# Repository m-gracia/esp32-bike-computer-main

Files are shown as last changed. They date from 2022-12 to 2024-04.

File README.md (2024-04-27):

# A motorcycle computer based on ESP32

## Contents

- [Synopsis](#synopsis)
- [Features](#features)
- [Part List](#part-list)
- [How to build one](#how-to-build-one)
- [Schemes and connections](#schemes-and-connections)
- [Improvements list](#improvements-list)
- [Acknowledgements](#acknowledgements)
- [Disclaimer](#disclaimer)

## Synopsis

A small homemade motorcycle computer based on ESP32 controller to show some usefull information.
The project has been done thinking on the modularity, so new features can be added (or removed).

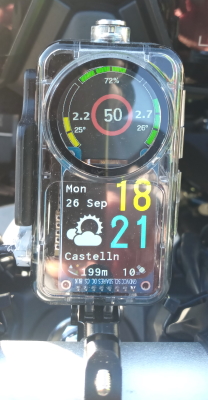
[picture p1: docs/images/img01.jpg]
ESP32 bike computer
<br>
*ESP32 bike computer mounted on a Yamaha Tracer 9*

## Features

- Android phone connection using mitchwongho application ([see acknowledgements](#acknowledgements)):
    - Shows the phone battery level.
    - Shows message alerts (Whatssapp, Telegram, SMS...).
- Tire pressure level, temperature and low battery alert from TPMS BLE sensors.
- Date, time and altitude from GPS.
- Weather prediction from OpenWeatherMap.
- Speed limit and street name from Microsoft Maps.
- Sends GPS latitude and longitude to a web server.
- Shows the location from the web server on a map.

### Other features not implemented

Some features have been removed from this version because there are not longer needed:

- Temperature using a waterproof DS1820
- ECU connection to KDS system (my old bike was a kawasaky). Here are some good information for those interested:
    - https://github.com/aster94/Keyword-Protocol-2000
    - https://github.com/HerrRiebmann/KDS2Bluetooth

## Part list

- **Wemos ESP32-S3 mini**<br>
    It could work with other ESP32 boards but I have chose this for the small size. Be sure to choose one with two cores, don't use a ESP32-C3 or ESP32-S2. I have use ESP32 mini D1 boards on other proyects, but the power IC included on some cheap boards doesn't provide enought power to keep wifi and bluetooth at the same time.
    
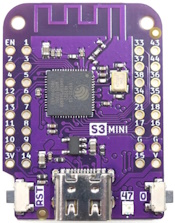
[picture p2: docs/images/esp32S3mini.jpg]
ESP32-S3 mini
    

- **GPS board Neo6M**<br>
    Don't forget to choose an apropiate antenna. It should work too with other smaller board like ATGM336H.

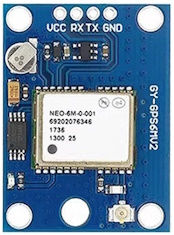
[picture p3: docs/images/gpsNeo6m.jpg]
Neo6M
    

- **SPI TFT**<br>
    One round 240x240 1,28" based on GC9A01 chip, and other square 240x280 1,69" based on ST7789 chip. These are cheap, fits on the case and they can be seen pretty clear under the sun light.

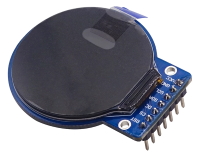
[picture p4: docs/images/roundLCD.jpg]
GC9A01 1,28" round LCD
    
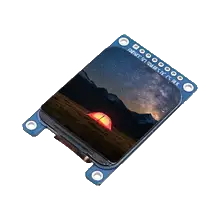
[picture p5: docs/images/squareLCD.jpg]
ST7789 1,69" square LCD
    

- **DJI Action2 case**<br>
    It is waterproof, both LCD's fits inside and you can remove one of the buttons to pass the cable through it. It has a standard gopro clip for holding it wherever you want. Choose the bracket that fits you better.

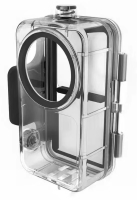
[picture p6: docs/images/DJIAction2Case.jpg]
DJI Action2 case
    
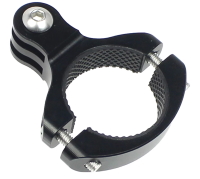
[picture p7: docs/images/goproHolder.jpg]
GoPro Holder
    

- **BLE 4.0 TPMS**<br>
    Bluetooth BLE 4.0 TPMS to control the tire pressure for Android / IOS application. Do not use BLE 5.0 model, is not supported by ESP32 at this moment.
    
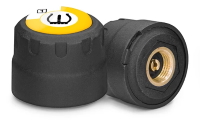
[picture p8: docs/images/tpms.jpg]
BLE4 TPMS
    

- **4G Wifi USB dongle**<br>
    USB Wifi - 4G router configured to create a hotspot for Internet connection. Must be connected to a USB connection on the bike.

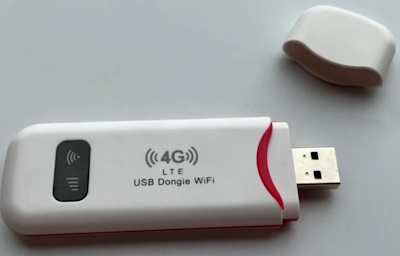
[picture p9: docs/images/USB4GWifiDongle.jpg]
USB 4G wifi router
    

- **Other stuff**
    - 2 * 8 pin 5cm dupond cables for LCDs.
    - 2 * 3x7cm PCB prototype breadboards.
    - USB male connector
    - Black USB-C cable.
    - Iron soldering kit.
    - Small silica gel bag for the LCD case. (Optional).    
    - Silicone thermal gun for sealing the junctions. (Optional).

## How to build one

1. Set a **public web server** to receive the information from the GPS and draw the route on a map.
If you do not want or need this function you can forget this step and comment the following line on "src/gprs.cpp" -> useGPRS():
```
// sendLocation();
```

Otherwise: 
- Download the files from [webpage](webpage) folder.
- Edit the sql scheme file, set your passwords and create a MariaDB database with the scheme and data to store the information.
- Edit the php files with your database server information.
- Save both php files on a folder served by the web server.

2. Get your OpenWeatherMap and Bing Maps API keys. You have to sign up on both services but the free tier should be enought.
     - https://openweathermap.org/api
     - https://www.bingmapsportal.com

3. Get all components and stuff listed below. They could be obtained from "all purpose" web pages like Aliexpress or Amazon.

4. Set your VCode + Platformio environment with the project from esp32-bike-computer-main folder. This step is too long to describe here and there is a lot of information on internet about how to do it :wink:
     - Create a "include/secrets.h" file and fill it with your data. E.g:
     ```
    #define TPMSMAC_FRONT "be:be:ca:fe:be:be"   //TPMS Front MAC Address
    #define TPMSMAC_REAR "ca:fe:be:be:ca:fe"    //TPMS Rear MAC Address
    #define HTTP_SERVER "my.server.com"
    #define HTTP_PATH "/bikefiles"   // Should begin with "/" and end without it
    #define WEATHER_APIKEY "yourOpenweathermapsAPIKey"
    #define WEATHER_CITYID "3104324"    // Zaragoza,ES Look for your location: https://www.openweathermap.org/find
    #define MAPS_APIKEY "yourBingMapsAPIKey"
    #define WEB_PASS "user_id0_pass_set_on_the_database"
    #define WIFI_SSID01 "SSID01_NAME"       // Configured on USB 4G Dongle
    #define WIFI_PASS01 "SSID01_PASSWORD"   // Configured on USB 4G Dongle
    #define WIFI_SSID02 "SSID02_NAME"       // Alternative. Eg: Phone hotspot
    #define WIFI_PASS02 "SSID02_PASSWORD"   // Alternative. Eg: Phone hotspot
     ```
     - Take a look on "include/my_def.h" and change some values if necessary:
     ``` 
     #define BT_DEVICE_NAME "Jarvis"     // BLE device name
     static unsigned char tpmsBatteyLow = 5;  // TPMS Battery low level
     static unsigned char tpmsLevelX = XX;    // TPMS Pressure levels
     #define TFT_TIMEMESSAGE 7000    // Phone alert message show time (7 sec)
     static TimeChangeRule CEST = {"CEST", Last, Sun, Mar, 2, 120};     // Central European Summer Time
     static TimeChangeRule CET = {"CET ", Last, Sun, Oct, 3, 60};       // Central European Standard Time

     ```
     - Compile and upload it to the ESP32. 
     - Upload the "data" folder files to ESP32 SPIFFS.

5. Build the PCB following the [schemes/main_v1.fzz](schemes/main_v1.fzz). Only the outer pins need to be solder.
     - [ESP32-S3 pinout](docs/esp32S3_pinout.png)

## Schemes and connections
There are some [Fritzing](https://fritzing.org/) schemes located on the [schemes](schemes) folder. They are designed for soldering on a quick breadboard.

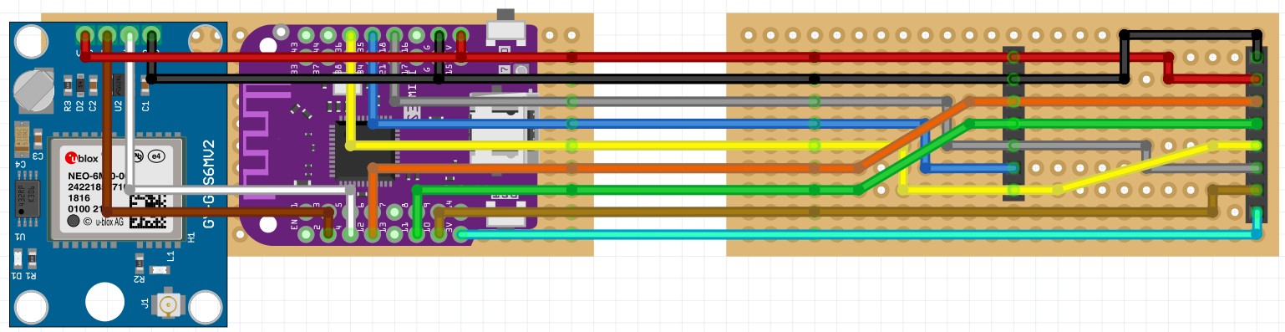
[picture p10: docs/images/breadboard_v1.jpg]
Breadboard Scheme


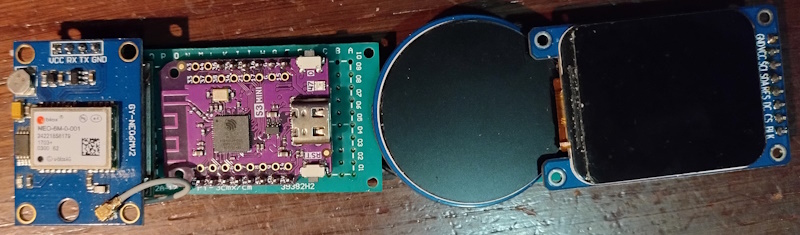
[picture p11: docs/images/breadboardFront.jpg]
Breadboard Front with plastic support


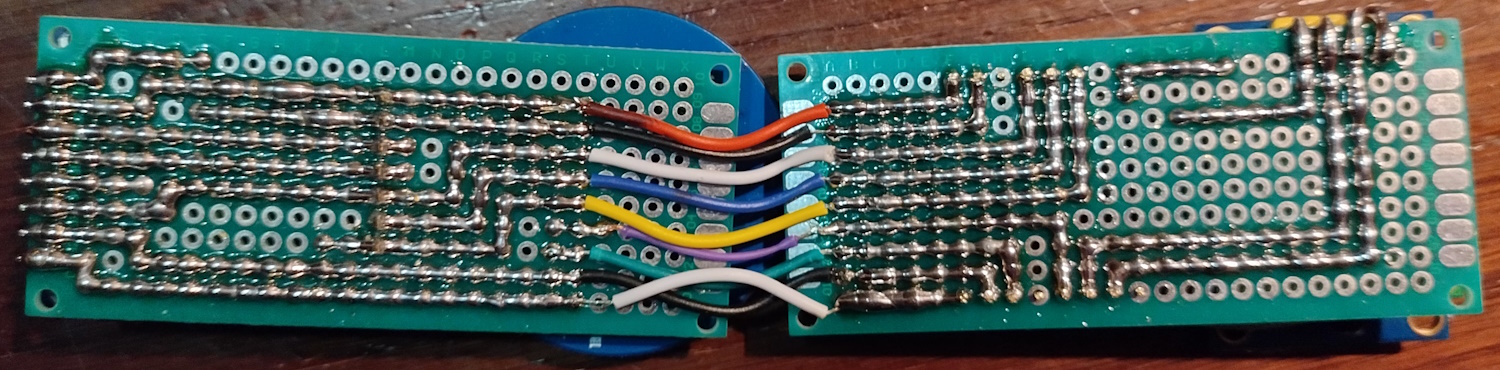
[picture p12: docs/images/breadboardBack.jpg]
Breadboard back


The connectors placement on the board are:
- Neo6M GPS: W10-T10
- ESP32 up: K10-F10
- Square LCD: "A" side external pins
- Round LCD: L9-L3

## Improvements list

- **Kickstand alert**<br>
    Using and ELM327 to communicate with the ECU, but I am not able to find the correct OBD PID. There are some projects to help with it, like: https://github.com/PowerBroker2/ELMduino

- **Turn by turn indications**<br>
    I am not able to find or build an application to send the indications by BLE. Maybe could find an aproach using Msoft Maps?...

- **Telegram communication**<br>
    To receive bike location and ¿maybe? set configuration

- **Web server for configuration**<br>
    To change some values (API keys, passwords...) and save it to the EEPROM.

- **Parking sensor.** ~~Because... Why not?~~ Done. Take a look at https://github.com/m-gracia/esp32-bike-computer-back

## Acknowledgements

Many thanks to the programmers that works and maintain the libraries used on this project, expecially @mitchwongho for his great application:

- <https://github.com/mitchwongho/ESP-Alerts-for-Arduino>
- <https://github.com/mitchwongho/ESP-Alerts-for-Android>
- <https://github.com/ra6070/BLE-TPMS>
- <https://github.com/olikraus/u8g2>
- <https://github.com/moononournation/Arduino_GFX>
- <https://github.com/JChristensen/Timezone>
- <https://github.com/mikalhart/TinyGPSPlus>
- <https://github.com/bblanchon/ArduinoJson>

And thank you VANEP and UniquePete for your Fritzing desigs: 
- <https://forum.fritzing.org/u/vanepp/summary>
- <https://forum.fritzing.org/u/UniquePete/summary>

## Disclaimer

I'm not a professional programmer neither an electronics expert, I'm just making this for fun and learn.

I want to share this to the community just in case someone else find it funny or usefull for his/her own project, I havent got other pretensions, so please:

1. I'm pretty sure the code is not perfectly written and does not follow the standars or etiquette, it just works for me. I will be more than pleasured to hear improvements and learn.
2. I have not tested so much this thing and sometimes it does have minor failures (GPS fail to get data, WIFI fails to connect to server...). I am happy with it but if you don't, please, don't waste your money.
3. Use at your own risk. I'm not responsible for any damages, direct or indirect. Remember: "It works for me" is the only test I have done.
4. I would be glad to read your comments, questions, doubts, jokes, etc. and will try to answer all of them, but I have made this on my spare time that is not so much, so don't expect a quick response. My apologies in advance.

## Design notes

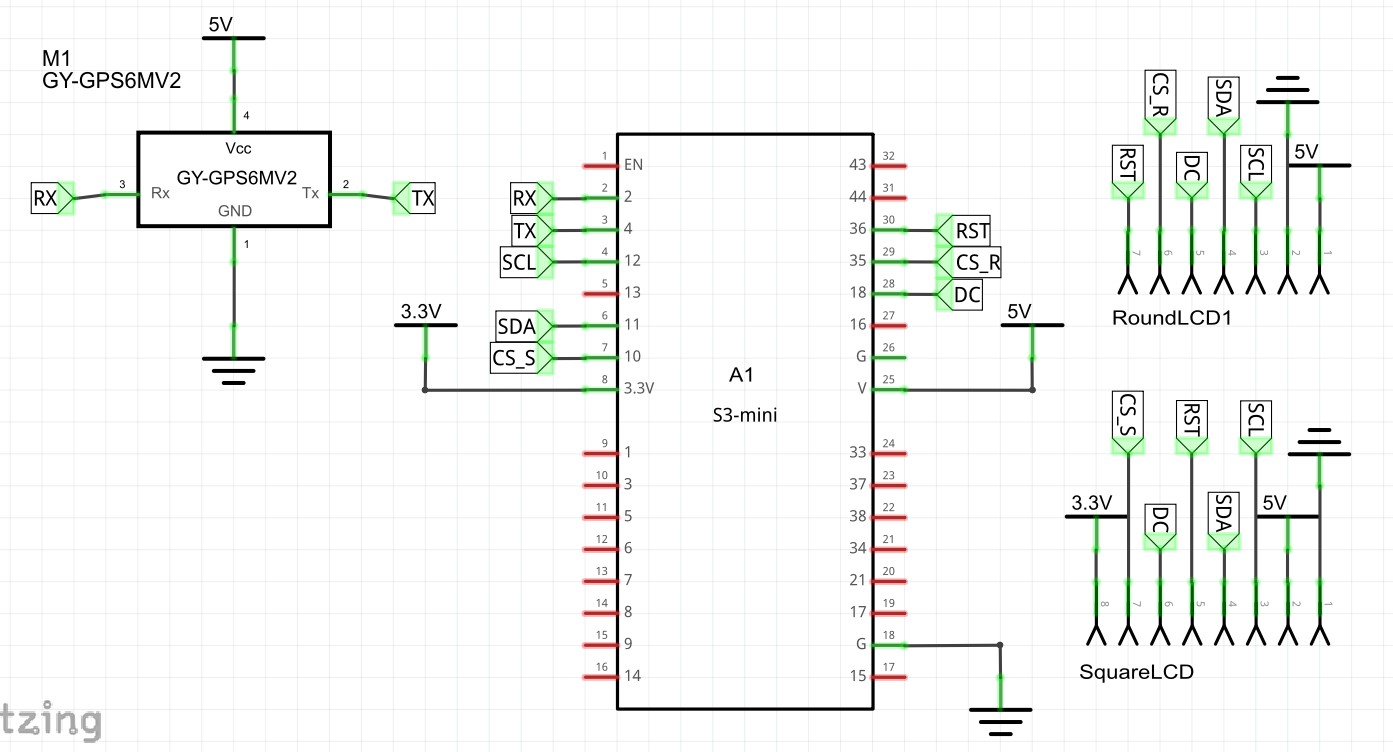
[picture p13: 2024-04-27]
docs/images/schematics_v1.jpg

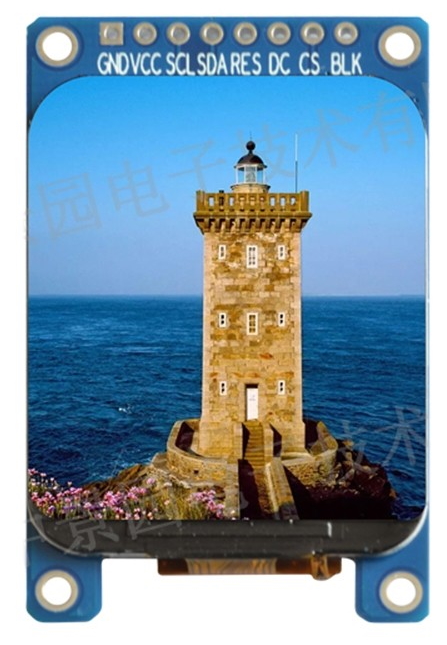
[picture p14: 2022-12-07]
docs/LCD_square_pinout.jpg

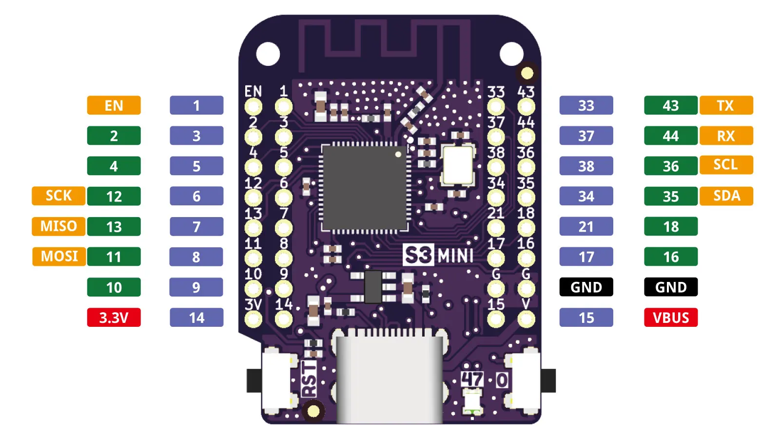
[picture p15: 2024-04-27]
docs/esp32S3_pinout.png

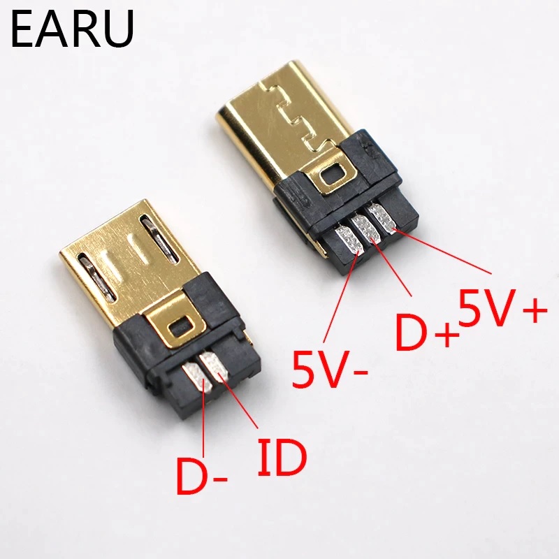
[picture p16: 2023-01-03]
docs/USB micro.jpg

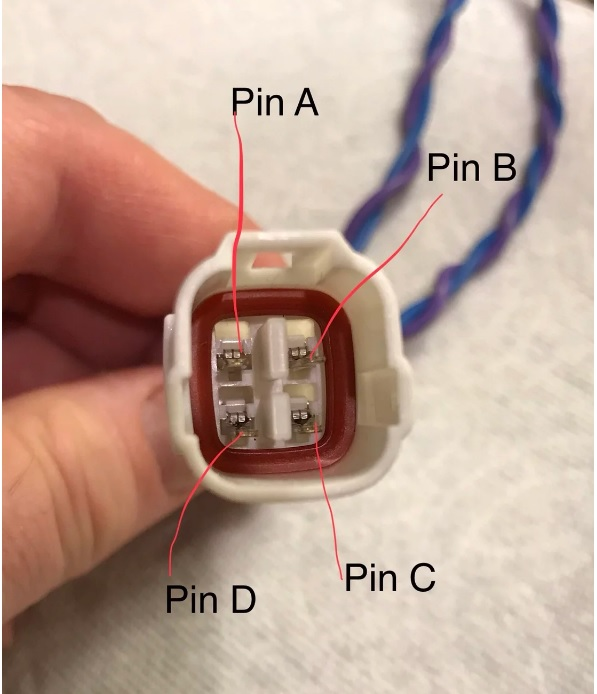
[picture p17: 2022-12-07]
docs/OBD_ELM327_02.png

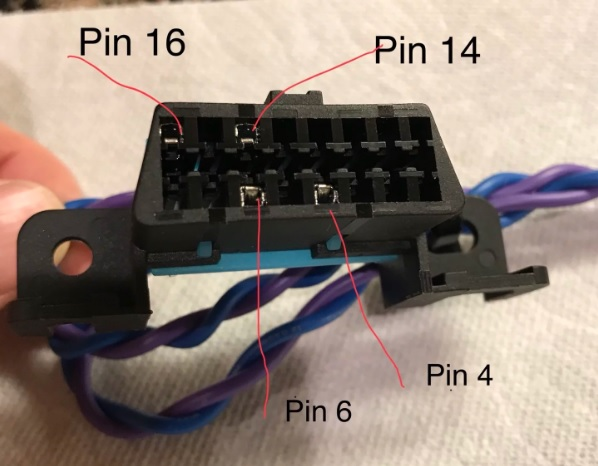
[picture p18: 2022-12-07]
docs/OBD_ELM327_03.png

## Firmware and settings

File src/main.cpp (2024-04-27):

#include <Arduino.h>
#include "my_def.h"
#include "my_debug.h"
#include "bluetooth.h"
#include "lcd.h"
#include "gps.h"
#include "gprs.h"
//#include "httpsrv.h"
#include "tpms.h"
#include "soc/soc.h"
#include "soc/rtc_cntl_reg.h"
//#include "soc/rtc_wdt.h"


// TASK ON CORE 0 //
void loopOthers (void * parameter){
  for(;;) {
    delay(20);    // For WDog feeding

    if(timerDisplay < millis()){
      sendDisplay();
      timerDisplay = millis() + 180; // Every 200ms min + time on GPS
    }

    feedGPS();    // Everytime
    //getWeb();
  }
}
// -------------- //


void setup() {
  //WRITE_PERI_REG(RTC_CNTL_BROWN_OUT_REG, 0); // Disable browout detector
  //rtc_wdt_protect_off(); // Disable watchdog
  //rtc_wdt_disable();
  //disableCore1WDT();
  //disableCore0WDT();

  pixel.begin();
  pixel.setBrightness(64);
  for(int i=0;i<6; i++){  // Wait until the current is stabilized 0,5s each loop
    pixel.clear(); pixel.show();
    delay(250);
    pixel.fill(0xFF0000); pixel.show(); // Red    
    delay(250);    
  }

  #ifdef DEBUG
    //Serial.begin(921600); 
    Serial.begin(115200);
  #endif
  DEBUG_PRINTLN("Manuel Gracia.Apr-2024");
  DEBUG_PRINTLN("https://github.com/m-gracia");
  DEBUG_PRINTLN("esp32-bike-computer_20240407");

  // Init Setup
  initDisplay();
  initGPS();
  initBT();
  initTPMS();
  initWifi();
  //initWeb();

  xTaskCreatePinnedToCore(
      loopOthers, // Function to implement the task
      "loopOthers", // Name of the task
      20000,  // Stack size in words
      NULL,  // Task input parameter
      1,  // Priority of the task
      &T_loopOthers,  // Task handle.
      0); // Core where the task should run
      
  pixel.clear(); pixel.show();
  DEBUG_PRINTLN("Setup end");
}

void loop() {
  if ((timerGPRS < millis() || timerWeather < millis() || timerMaps < millis()) 
    && bikeGPRS != STATUS_UNK){
      pixel.fill(0x00FF00); pixel.show(); // Green
      useGPRS();
      pixel.clear(); pixel.show();
  }

  if (timerTPMS < millis()){
    pixel.fill(0x0000FF);  pixel.show(); // Blue
    getTPMS();
    timerTPMS = millis() + (BTSCANTIME * 1000) + 200; // 5 sec
    pixel.clear(); pixel.show();
  }

  if (timerGPS < millis() && bikeGPS != STATUS_UNK){
    pixel.fill(0xB200FF);  pixel.show(); // Purple
    getGPS(); // Every time
    timerGPS = millis() + 1000;  // 1s
    pixel.clear(); pixel.show();
  }
}

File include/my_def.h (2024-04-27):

#ifndef _MY_DEF_H_
#define _MY_DEF_H_
#include <Arduino.h>
#include "secrets.h" // To store secret information used here. You must create first. Look on https://github.com/m-gracia for the contents.

// Bluetooth
// https://specificationrefs.bluetooth.com/assigned-values/Appearance%20Values.pdf
#define BT_GENERIC_DISPLAY 320
#define BT_VEHICLE_MOTORBIKE 2244
#define BT_DEVICE_NAME "Jarvis"     // BLE device name
#include <BLEDevice.h>
#include <BLEUtils.h>
#include <BLEAdvertisedDevice.h>
#include <BLEAddress.h>
static const BLEUUID ALERT_DISPLAY_SERVICE_UUID = BLEUUID("cb99fdf2-bebe-cafe-b1bf-bf9803b2df00");          
static const BLEUUID DISPLAY_MESSAGE_CHARACTERISTIC_UUID = BLEUUID("cb99fdf2-bebe-cafe-b1bf-bf9803b2df00");     // Notification text
static const BLEUUID DISPLAY_TIME_CHARACTERISTIC_UUID = BLEUUID("b7b0a14b-3e94-488f-b262-5d584a1ef9e1");        // Time and phone battery
static const BLEUUID DISPLAY_DISPLAY_ORIENTATION_CHARACTERISTIC_UUID = BLEUUID("0070b87e-d825-43f5-be0c-7d86f75e4900");  // Not needed
static const BLEUUID MOTORBIKE_SERVICE_UUID = BLEUUID("cb99fdf2-bebe-cafe-b1bf-bf9803b2df01");
static const BLEUUID DISTANCE_CHARACTERISTIC_UUID = BLEUUID("cb99fdf2-bebe-cafe-b1bf-bf9803b2df01");            // Distance
extern int bikePhoneBattery;       // Phone battery

// TPMS
#define BTSCANTIME 5
#include <BLEScan.h>
static BLEAddress *pServerAddress;
static String TPMS_knownAddresses[] = { TPMSMAC_FRONT , TPMSMAC_REAR};  // TPMS sensors MAC: Front , Rear
static unsigned char tpmsBatteyLow = 5;  // TPMS Battery low level
static unsigned char tpmsLevel4 = 35;    // TPMS Pressure very high level
static unsigned char tpmsLevel3 = 32;    // TPMS Pressure high level
static unsigned char tpmsLevel2 = 23;    // TPMS Pressure low level
static unsigned char tpmsLevel1 = 21;    // TPMS Pressure very low level
extern BLEScan* pBLEScan;
extern int bikeTPMSF;       // TPMS Front Pressure data
extern int bikeTPMSFTemp;   // TPMS Front Temperature data
extern int bikeTPMSFBatt;   // TPMS Front Battery data
extern int bikeTPMSR;       // TPMS Rear Pressure data
extern int bikeTPMSRTemp;   // TPMS Rear Temperature data
extern int bikeTPMSRBatt;   // TPMS Rear Battery data

// LCD
// #define TFT_GFX_SCK 12   // SCL PIN ESP32-S3_v0
// #define TFT_GFX_MOSI 11  // SDA PIN ESP32-S3_v0
// #define TFT_GFX_MISO GFX_NOT_DEFINED // Not used on this LCD's
// #define TFT_GFX_RESET  GFX_NOT_DEFINED //2   // Just testing
#define TFT_GFX_SCK 12   // SCL PIN ESP32-S3_v1
#define TFT_GFX_MOSI 11  // SDA PIN ESP32-S3_v1
#define TFT_GFX_MISO GFX_NOT_DEFINED // Not used on this LCD's
#define TFT_GFX_RESET 36 // ESP32-S3_v1


#include <SPI.h>
#include <U8g2lib.h> //v2.32.15 https://github.com/olikraus/u8g2
#include <FS.h>
#include <SPIFFS.h>
#include <Arduino_GFX_Library.h>    //v1.2.3 https://github.com/moononournation/Arduino_GFX
#include "BmpClass.h"
// static Arduino_DataBus *bus1 = new Arduino_ESP32SPI(35 /* DC */, 36 /* CS */, TFT_GFX_SCK, TFT_GFX_MOSI, TFT_GFX_MISO, HSPI /* spi_num */); //ESP32-S3_v0
// static Arduino_GFX *tftR = new Arduino_GC9A01(bus1, TFT_GFX_RESET, 0 /* rotation */, true /*IPS*/); // ESP32-S3_v0
// static Arduino_DataBus *bus2 = new Arduino_ESP32SPI(35 /* DC */, 18 /* CS 26 default */, TFT_GFX_SCK, TFT_GFX_MOSI, TFT_GFX_MISO, HSPI /* spi_num */); // ESP32-S3_v0
// static Arduino_GFX *tftS = new Arduino_ST7789(bus2, TFT_GFX_RESET, 2 /* rotation */, true /*IPS*/, 240 /* width */, 280 /* height */,0,0,0,20 ); // ESP32-S3_v0

static Arduino_DataBus *bus1 = new Arduino_ESP32SPI(18 /* DC */, 35 /* CS */, TFT_GFX_SCK, TFT_GFX_MOSI, TFT_GFX_MISO, HSPI /* spi_num */); //ESP32-S3_v1
static Arduino_GFX *tftR = new Arduino_GC9A01(bus1, GFX_NOT_DEFINED, 0 /* rotation */, true /*IPS*/); // ESP32-S3_v1
static Arduino_DataBus *bus2 = new Arduino_ESP32SPI(18 /* DC */, 10 /* CS 26 default */, TFT_GFX_SCK, TFT_GFX_MOSI, TFT_GFX_MISO, HSPI /* spi_num */); // ESP32-S3_v1
static Arduino_GFX *tftS = new Arduino_ST7789(bus2, TFT_GFX_RESET, 2 /* rotation */, true /*IPS*/, 240 /* width */, 280 /* height */,0,0,0,20 ); // ESP32-S3_v1


#define FONT_SIGNAL u8g2_font_fub30_tn 
#define FONT_BIG u8g2_font_logisoso92_tn
#define FONT_MEDIUM2 u8g2_font_inb21_mr
//#define FONT_MEDIUM u8g2_font_lubB18_tf
//#define FONT_MEDIUM2 u8g2_font_logisoso24_tr
#define FONT_MEDIUM u8g2_font_luBS18_tr 
#define FONT_SMALL u8g2_font_helvB14_tf
#define TFT_TIMEMESSAGE 7000    // Phone alert message show time (7 sec)
extern String tftMsgTitle;      // Phone msg Title received
extern String tftMsgBody;       // Phone msg Body received
extern String tftMsgApp;        // Phone msg Application received

// Time
#include <Time.h>
#include <TimeLib.h>
#include <Timezone.h>   // https://github.com/JChristensen/Timezone
static TimeChangeRule CEST = {"CEST", Last, Sun, Mar, 2, 120};     // Central European Summer Time
static TimeChangeRule CET = {"CET ", Last, Sun, Oct, 3, 60};       // Central European Standard Time
static Timezone CE(CEST, CET);
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

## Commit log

2022-12-28 Breadboard images and schemes. Updated README.
    [main.fzz, main_v2.fzz]
2022-12-28 Updated schemes and cable colours
    [display.fzz, main.fzz, main_v2.fzz]
2022-12-28 Corrected display scheme and cable colours
    [main_v2.fzz]
2023-01-03 Simplified gprs files. Change GPRS TX pin
    [main.fzz, main_v2.fzz]
2023-01-06 Updated documentation and added 3D designs
    [WaterproofBox-latch.stl, WaterproofBox-lid.stl, WaterproofBox.stl]
2023-01-29 Blink onboard led while on setup
2023-01-29 Slim case version
    [WaterproofBox-latch slim.stl, WaterproofBox-lid slim.stl]
2023-02-05 Basic web server
    [partitions.csv]
2023-05-01 Changed memory scheme to allow coredump
    [huge_app.csv]
2023-05-01 Faster UART for debug
2023-05-01 Changed maps timer time to 20s
2023-05-01 Quicker led blinking on boot
2023-06-25 Changed to use lolin ESP32-S3 mini
2024-03-15 Replaced gprs+gps module by gps module and wifi
    [httpsrv.cpp, main.cpp, my_def.h]
2024-03-16 Updated to use ArduinoJson v7
2024-03-16 Cleaned old comments from ArduinoJson v5
2024-03-17 UART GPS Speed to default
2024-03-17 Fixed bug with GPRS icon
    [lcd.cpp, main.cpp, my_def.h]
2024-03-21 Updated schematics
    [main_v1.fzz]
2024-04-03 Fixed bug when reseting LCD
    [my_def.h]
2024-04-03 Updated documentation
    [WaterproofBox-latch slim.stl, WaterproofBox-latch.stl, WaterproofBox-lid slim.stl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]
